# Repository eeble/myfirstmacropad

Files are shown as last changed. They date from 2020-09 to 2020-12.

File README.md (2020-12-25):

# myfirstmacropad
My First Macro Pad

I'll try to keep this updated.

<br />This work is licensed under a <a rel="license" href="http://creativecommons.org/licenses/by-sa/4.0/">Creative Commons Attribution-ShareAlike 4.0 International License</a>.

This macropad will use QMK as its firmware. QMK is also open source and available from https://qmk.fm/

### Front and Back renders
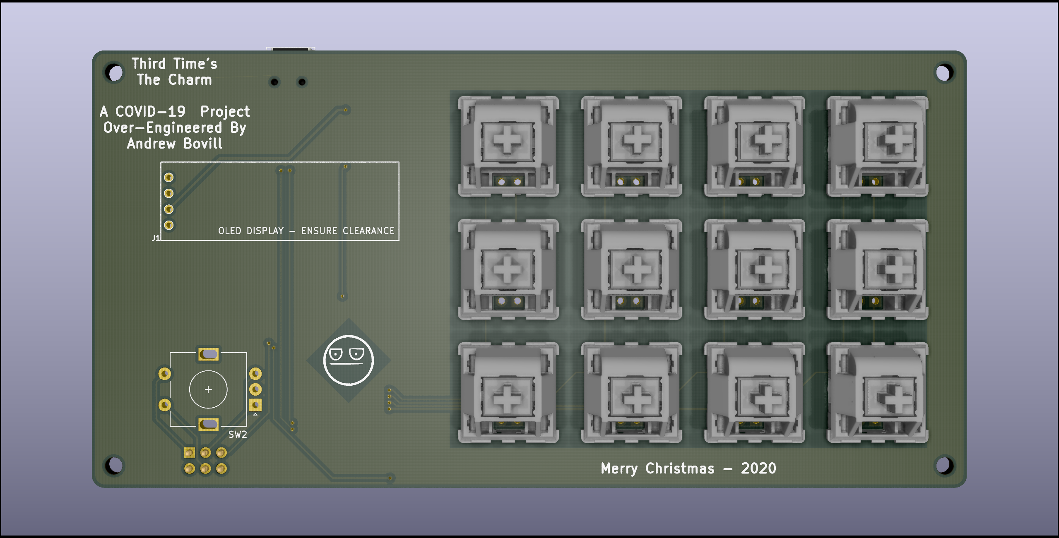
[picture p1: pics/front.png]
Front

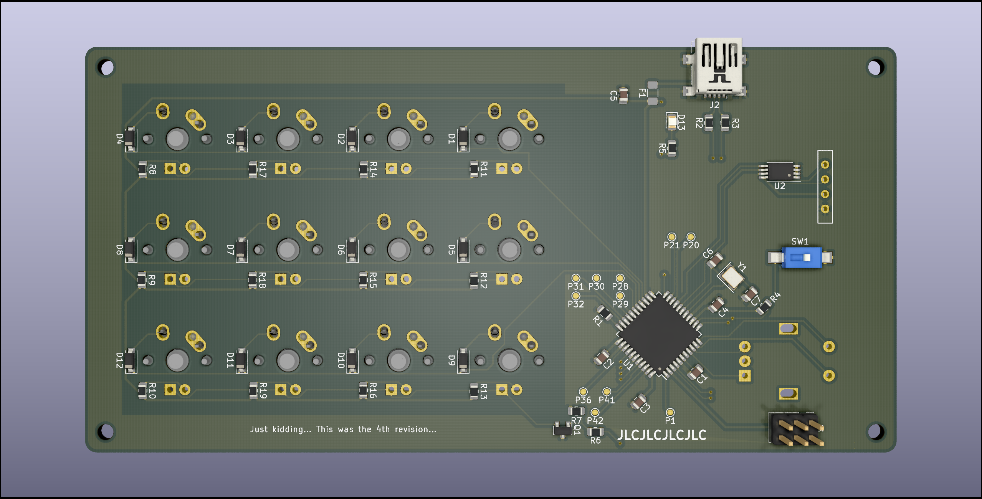
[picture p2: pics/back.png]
Back


### BOM
Interactive [BOM](kicad/bom/ibom.html)

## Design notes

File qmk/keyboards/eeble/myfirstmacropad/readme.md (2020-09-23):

# myfirstmacropad

dumbpad

A 4x4 macro/numpad with rotary encoder.

Keyboard Maintainer: [imchipwood](https://github.com/imchipwood)

PCB repository: https://github.com/imchipwood/dumbpad

Make example for this keyboard (after setting up your build environment):

    make dumbpad:default

Program with:

    make dumbpad:default:avrdude

See the [build environment setup](https://docs.qmk.fm/#/getting_started_build_tools) and the [make instructions](https://docs.qmk.fm/#/getting_started_make_guide) for more information. Brand new to QMK? Start with our [Complete Newbs Guide](https://docs.qmk.fm/#/newbs).

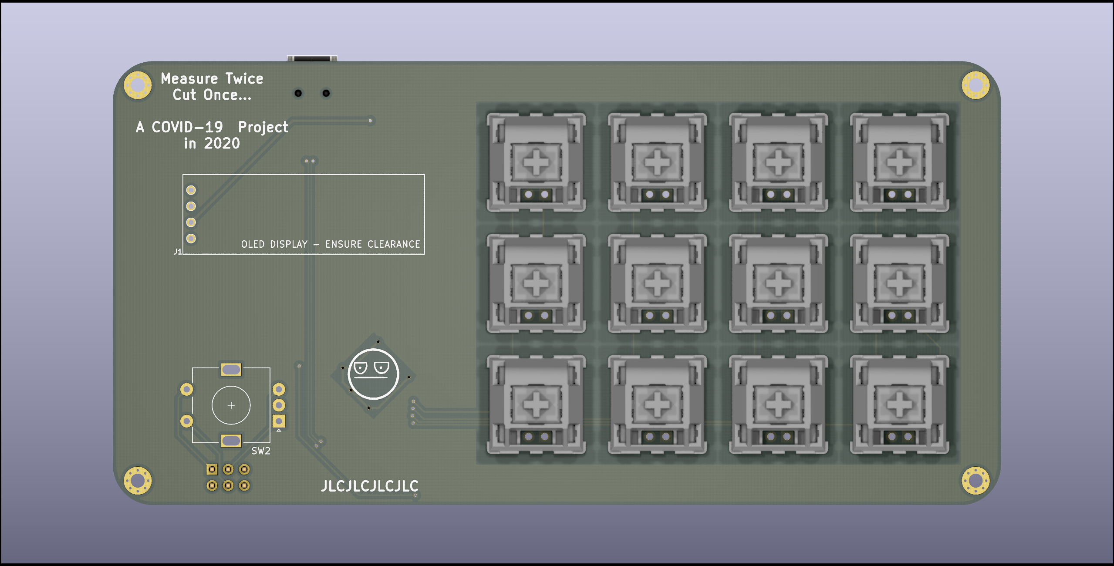
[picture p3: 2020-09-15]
kicad/pics/front.png

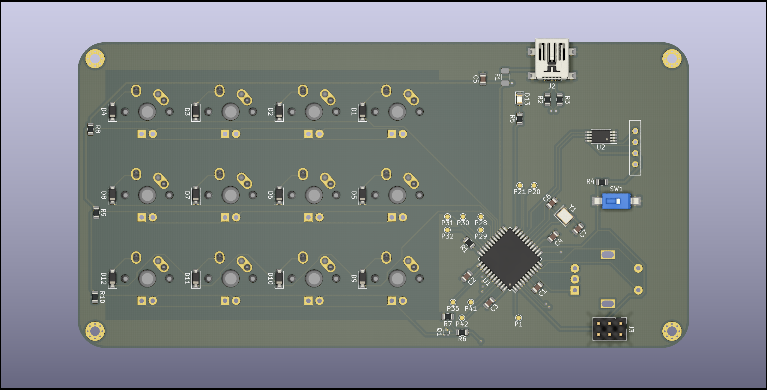
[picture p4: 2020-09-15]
kicad/pics/back.png

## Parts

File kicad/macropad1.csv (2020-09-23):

Id | Designator | Package | Quantity | Designation | Supplier and ref
1 | U1 | TQFP-44_10x10mm_P0.8mm | 1 | ATmega32U4-AU
2 | J2 | USB_Mini-B_Lumberg_2486_01_Horizontal | 1 | USB_B_Mini
3 | MX1,MX2,MX3,MX4,MX5,MX6,MX7,MX8,MX9,MX10,MX11,MX12 | MX-1U | 12 | MX-LED
4 | REF**,REF**,REF**,REF** | MountingHole_2.2mm_M2_Pad_Via | 4 | MountingHole_2.2mm_M2_Pad_Via
5 | SW2 | RotaryEncoder_Alps_EC11E-Switch_Vertical_H20mm | 1 | Rotary_Encoder_Switch
6 | G*** | unamused_sm | 1 | LOGO
7 | J1 | OLED_0.91in_4pin | 1 | Conn_01x04
8 | R3,R2 | R_0805_2012Metric | 2 | 22
9 | Y1 | Crystal_SMD_3225-4Pin_3.2x2.5mm_HandSoldering | 1 | 16Mhz
10 | SW1 | SW_SPST_REED_CT05-XXXX-G1 | 1 | SW_Reed
11 | R4,R1 | R_0805_2012Metric | 2 | 10k
12 | F1 | Fuse_1206_3216Metric | 1 | 500mA
13 | D12,D11,D10,D9,D8,D7,D6,D5,D4,D3,D2,D1 | D_SOD-123 | 12 | D_Small
14 | C7,C6 | C_0805_2012Metric | 2 | 22pF
15 | C5 | C_0805_2012Metric | 1 | 10uF
16 | C4,C3,C2 | C_0805_2012Metric | 3 | 0.1uF
17 | C1 | C_0805_2012Metric | 1 | 1uF

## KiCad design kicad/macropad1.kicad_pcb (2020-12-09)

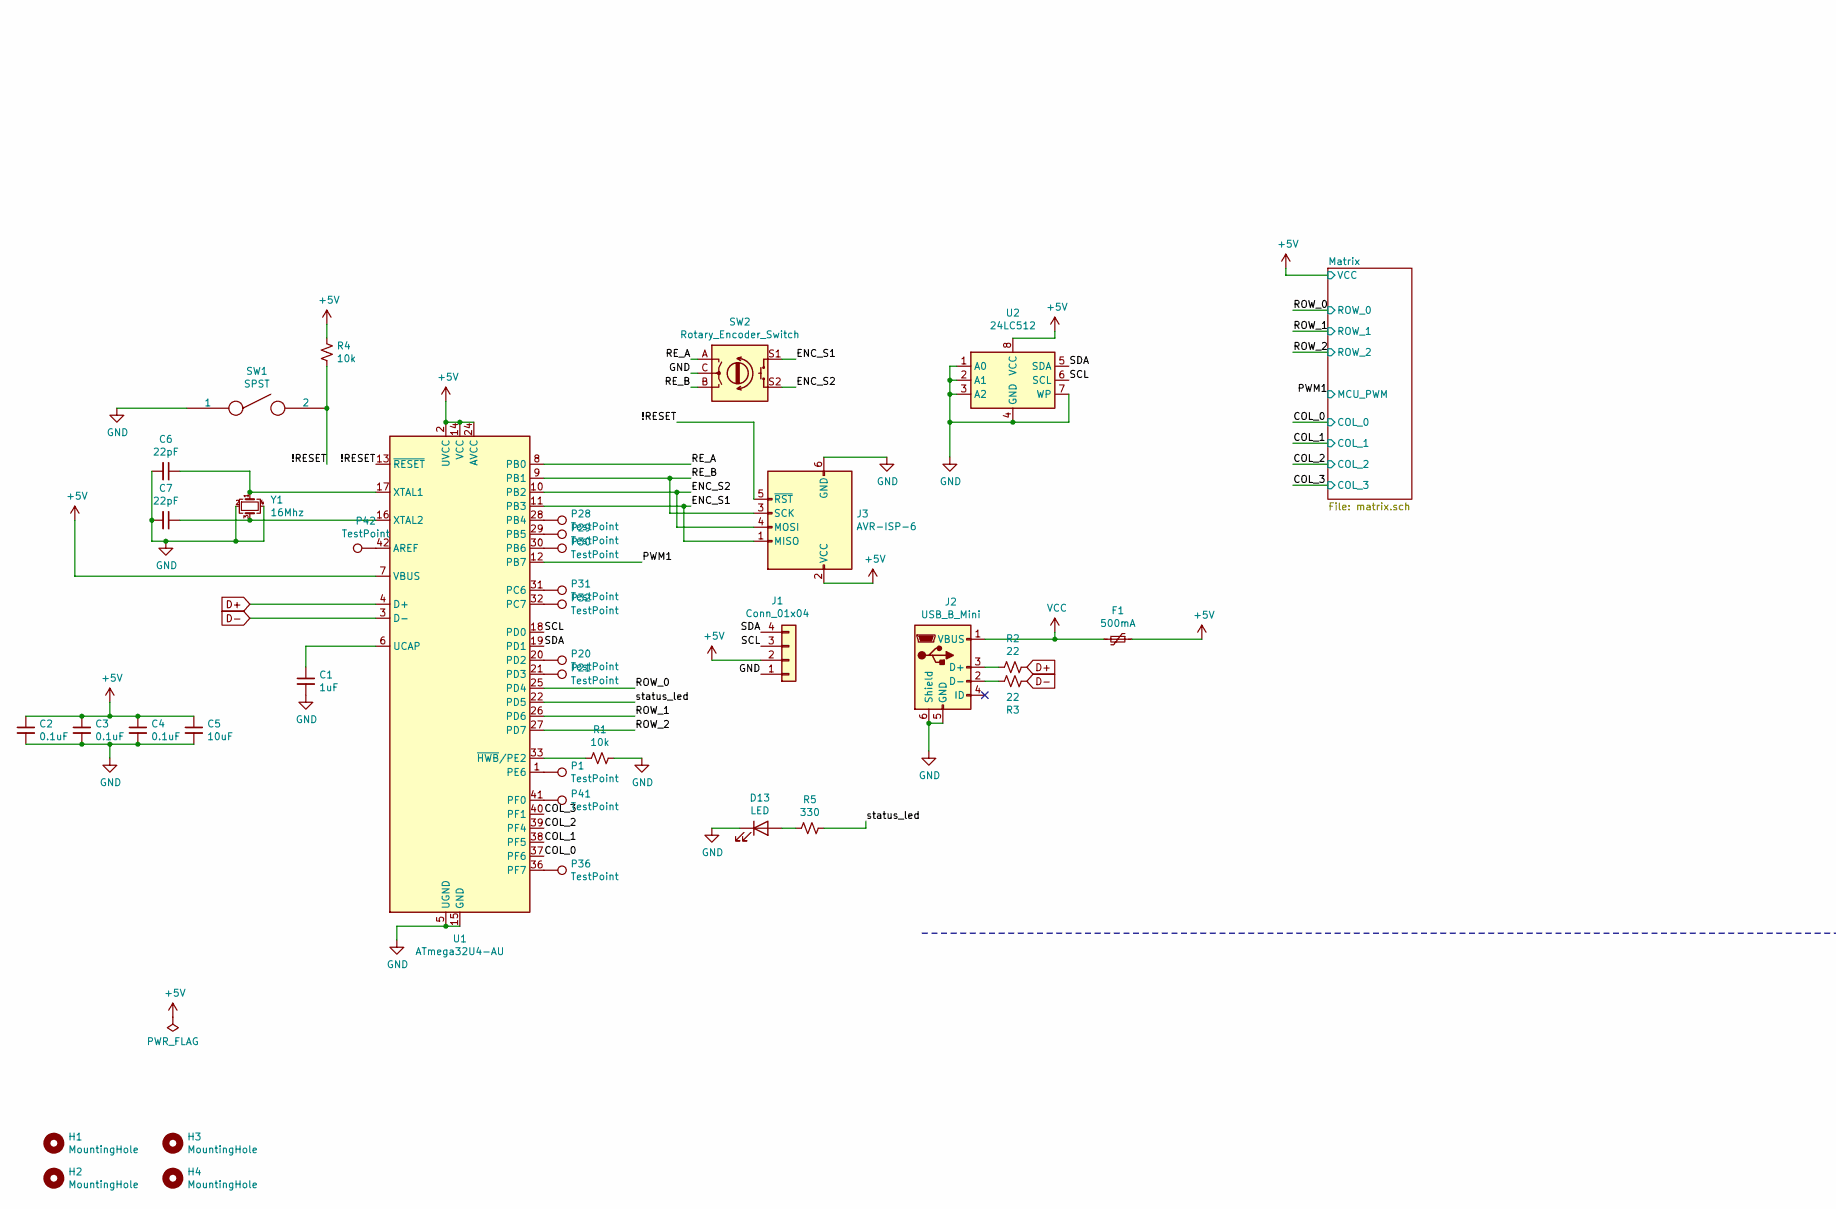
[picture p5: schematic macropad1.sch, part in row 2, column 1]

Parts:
C1: 1uF; C_0805_2012Metric
C2, C3, C4: 0.1uF; C_0805_2012Metric
C5: 10uF; C_0805_2012Metric
C6, C7: 22pF; C_0805_2012Metric
D13: LED; LED_0805_2012Metric
F1: 500mA; Fuse_1206_3216Metric
H1, H2, H3, H4: MountingHole; MountingHole_2.7mm_M2.5
J1: Conn_01x04; OLED_0.91in_4pin
J2: USB_B_Mini; USB_Mini-B_Lumberg_2486_01_Horizontal
J3: AVR-ISP-6; PinHeader_2x03_P2.54mm_Vertical
P1, P20, P21, P28, P29, P30, P31, P32, P36, P41, P42: TestPoint; TestPoint_Pad_D1.0mm
R1, R4: 10k; R_0805_2012Metric
R2, R3: 22; R_0805_2012Metric
R5: 330; R_0805_2012Metric
SW1: SPST; SW_SPST_REED_CT05-XXXX-G1
SW2: Rotary_Encoder_Switch; RotaryEncoder_Alps_EC11E-Switch_Vertical_H20mm
U1: ATmega32U4-AU; TQFP-44_10x10mm_P0.8mm
U2: 24LC512; TSSOP-8_4.4x3mm_P0.65mm
Y1: 16Mhz; Crystal_SMD_3225-4Pin_3.2x2.5mm

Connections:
+5V: C2.1, C3.1, C4.1, C5.1, F1.1, J1.2, J3.2 (VCC), R4.1, U1.2 (UVCC), U1.7 (VBUS), U1.14 (VCC), U1.24 (AVCC), U1.34 (VCC), U1.44 (AVCC), U2.8 (VCC); also elsewhere on the board
/!RESET: J3.5 (~RST), R4.2, SW1.2, U1.13 (~RESET)
/COL_0: U1.37 (PF6); also elsewhere on the board
/COL_1: U1.38 (PF5); also elsewhere on the board
/COL_2: U1.39 (PF4); also elsewhere on the board
/COL_3: U1.40 (PF1); also elsewhere on the board
/ENC_S1: J3.1 (MISO), SW2.S1, U1.11 (PB3)
/ENC_S2: J3.4 (MOSI), SW2.S2, U1.10 (PB2)
/PWM1: U1.12 (PB7); also elsewhere on the board
/RE_A: SW2.A, U1.8 (PB0)
/RE_B: J3.3 (SCK), SW2.B, U1.9 (PB1)
/ROW_0: U1.25 (PD4); also elsewhere on the board
/ROW_1: U1.26 (PD6); also elsewhere on the board
/ROW_2: U1.27 (PD7); also elsewhere on the board
/SCL: J1.3, U1.18 (PD0), U2.6 (SCL)
/SDA: J1.4, U1.19 (PD1), U2.5 (SDA)
/status_led: R5.1, U1.22 (PD5)
D+: R2.1, U1.4 (D+)
D-: R3.2, U1.3 (D-)
GND: C1.2, C2.2, C3.2, C4.2, C5.2, C6.2, C7.2, D13.1 (K), J1.1, J2.5 (GND), J2.6 (Shield), J3.6 (GND), R1.1, SW1.1, SW2.C, U1.5 (UGND), U1.15 (GND), U1.23 (GND), U1.35 (GND), U1.43 (GND), U2.1 (A0), U2.2 (A1), U2.3 (A2), U2.4 (GND), U2.7 (WP), Y1.2, Y1.4; also elsewhere on the board
unnamed: C1.1, U1.6 (UCAP)
unnamed: C6.1, U1.17 (XTAL1), Y1.1
unnamed: C7.1, U1.16 (XTAL2), Y1.3
unnamed: D13.2 (A), R5.2
unnamed: J2.2 (D-), R3.1
unnamed: J2.3 (D+), R2.2
unnamed: P1.1, U1.1 (PE6)
unnamed: P20.1, U1.20 (PD2)
unnamed: P21.1, U1.21 (PD3)
unnamed: P28.1, U1.28 (PB4)
unnamed: P29.1, U1.29 (PB5)
unnamed: P30.1, U1.30 (PB6)
unnamed: P31.1, U1.31 (PC6)
unnamed: P32.1, U1.32 (PC7)
unnamed: P36.1, U1.36 (PF7)
unnamed: P41.1, U1.41 (PF0)
unnamed: P42.1, U1.42 (AREF)
unnamed: R1.2, U1.33 (~HWB~/PE2)
VCC: F1.2, J2.1 (VBUS)

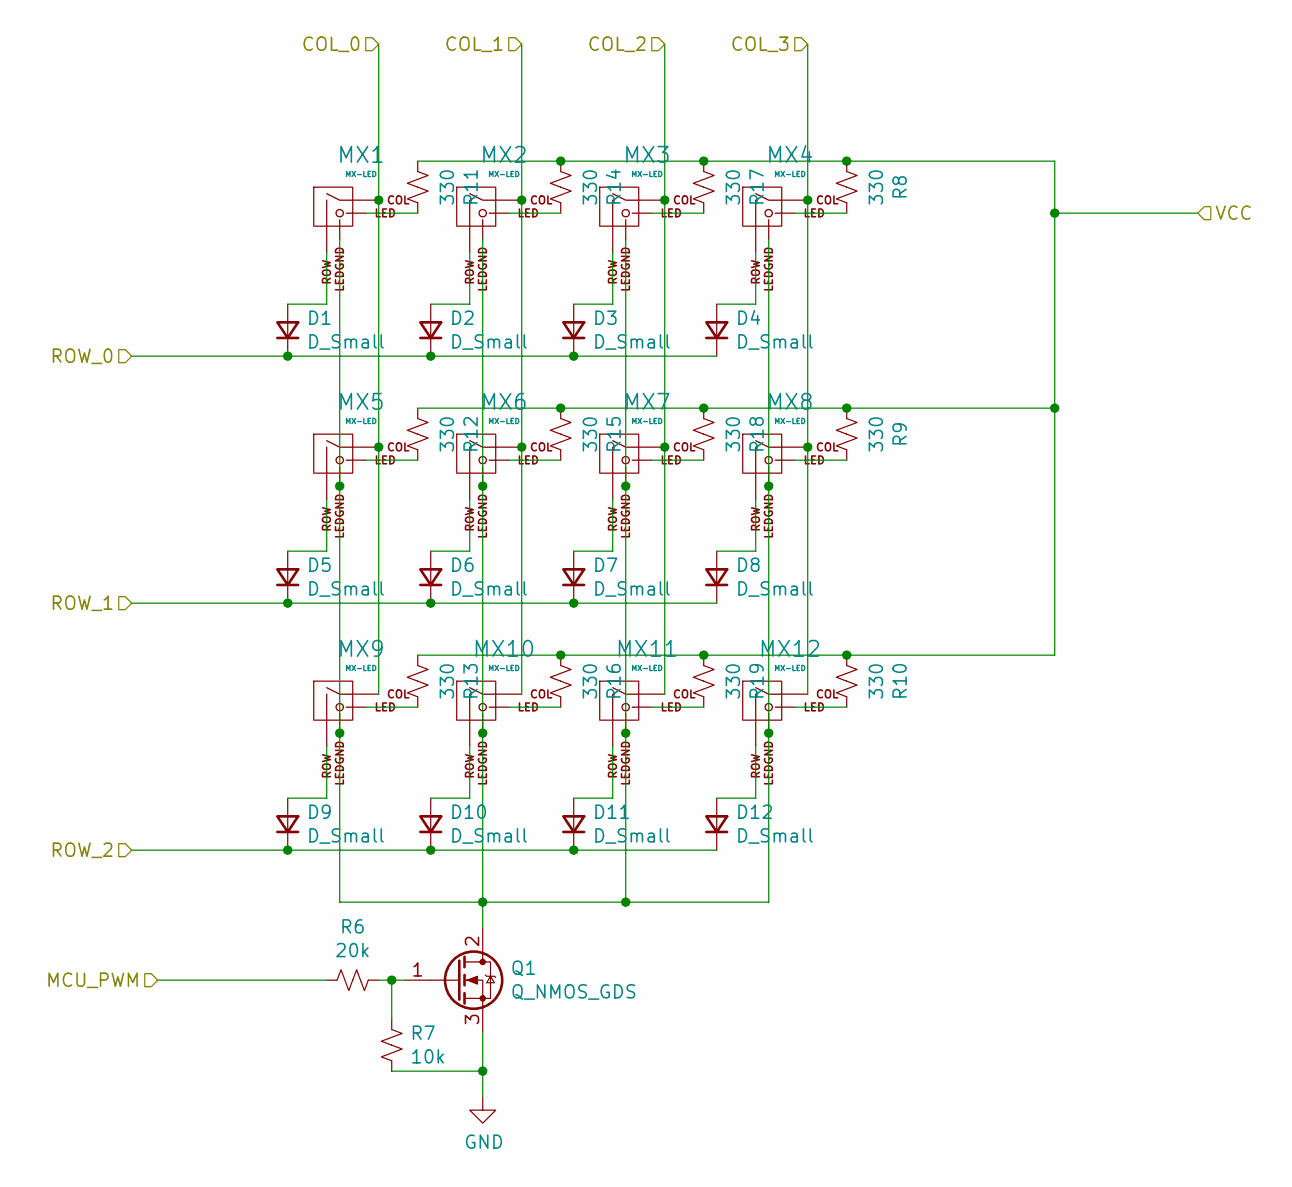
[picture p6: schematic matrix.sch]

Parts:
D1, D2, D3, D4, D5, D6, D7, D8, D9, D10, D11, D12: D_Small; D_SOD-123
MX1, MX2, MX3, MX4, MX5, MX6, MX7, MX8, MX9, MX10, MX11, MX12: MX-LED; MX-1U
Q1: Q_NMOS_GDS; SOT-23
R6: 20k; R_0805_2012Metric
R7: 10k; R_0805_2012Metric
R8, R9, R10, R11, R12, R13, R14, R15, R16, R17, R18, R19: 330; R_0805_2012Metric

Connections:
+5V: R8.2, R9.2, R10.2, R11.2, R12.2, R13.2, R14.2, R15.2, R16.2, R17.2, R18.2, R19.2; also elsewhere on the board
/COL_0: MX1.1 (COL), MX5.1 (COL), MX9.1 (COL); also elsewhere on the board
/COL_1: MX2.1 (COL), MX6.1 (COL), MX10.1 (COL); also elsewhere on the board
/COL_2: MX3.1 (COL), MX7.1 (COL), MX11.1 (COL); also elsewhere on the board
/COL_3: MX4.1 (COL), MX8.1 (COL), MX12.1 (COL); also elsewhere on the board
/PWM1: R6.2; also elsewhere on the board
/ROW_0: D1.1 (K), D2.1 (K), D3.1 (K), D4.1 (K); also elsewhere on the board
/ROW_1: D5.1 (K), D6.1 (K), D7.1 (K), D8.1 (K); also elsewhere on the board
/ROW_2: D9.1 (K), D10.1 (K), D11.1 (K), D12.1 (K); also elsewhere on the board
GND: Q1.3 (S), R7.2; also elsewhere on the board
unnamed: D1.2 (A), MX1.2 (ROW)
unnamed: D2.2 (A), MX2.2 (ROW)
unnamed: D3.2 (A), MX3.2 (ROW)
unnamed: D4.2 (A), MX4.2 (ROW)
unnamed: D5.2 (A), MX5.2 (ROW)
unnamed: D6.2 (A), MX6.2 (ROW)
unnamed: D7.2 (A), MX7.2 (ROW)
unnamed: D8.2 (A), MX8.2 (ROW)
unnamed: D9.2 (A), MX9.2 (ROW)
unnamed: D10.2 (A), MX10.2 (ROW)
unnamed: D11.2 (A), MX11.2 (ROW)
unnamed: D12.2 (A), MX12.2 (ROW)
unnamed: MX1.3 (LED), R11.1
unnamed: MX1.4 (LEDGND), MX2.4 (LEDGND), MX3.4 (LEDGND), MX4.4 (LEDGND), MX5.4 (LEDGND), MX6.4 (LEDGND), MX7.4 (LEDGND), MX8.4 (LEDGND), MX9.4 (LEDGND), MX10.4 (LEDGND), MX11.4 (LEDGND), MX12.4 (LEDGND), Q1.2 (D)
unnamed: MX2.3 (LED), R14.1
unnamed: MX3.3 (LED), R17.1
unnamed: MX4.3 (LED), R8.1
unnamed: MX5.3 (LED), R12.1
unnamed: MX6.3 (LED), R15.1
unnamed: MX7.3 (LED), R18.1
unnamed: MX8.3 (LED), R9.1
unnamed: MX9.3 (LED), R13.1
unnamed: MX10.3 (LED), R16.1
unnamed: MX11.3 (LED), R19.1
unnamed: MX12.3 (LED), R10.1
unnamed: Q1.1 (G), R6.1, R7.1

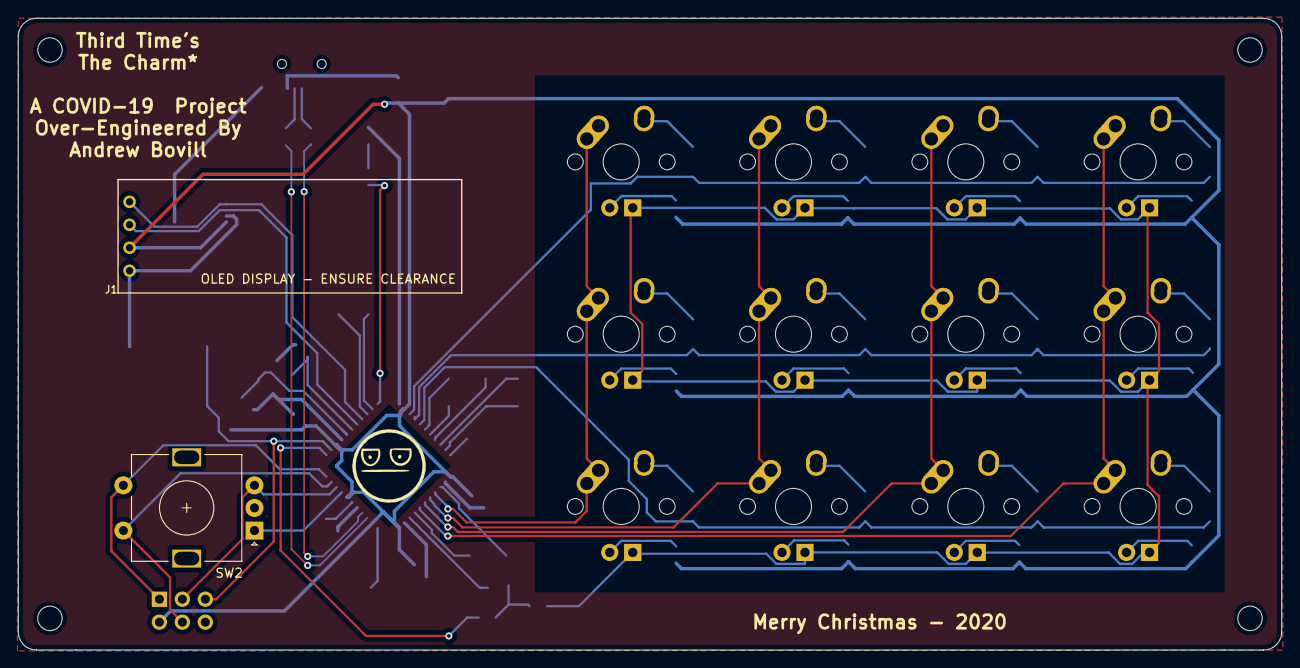
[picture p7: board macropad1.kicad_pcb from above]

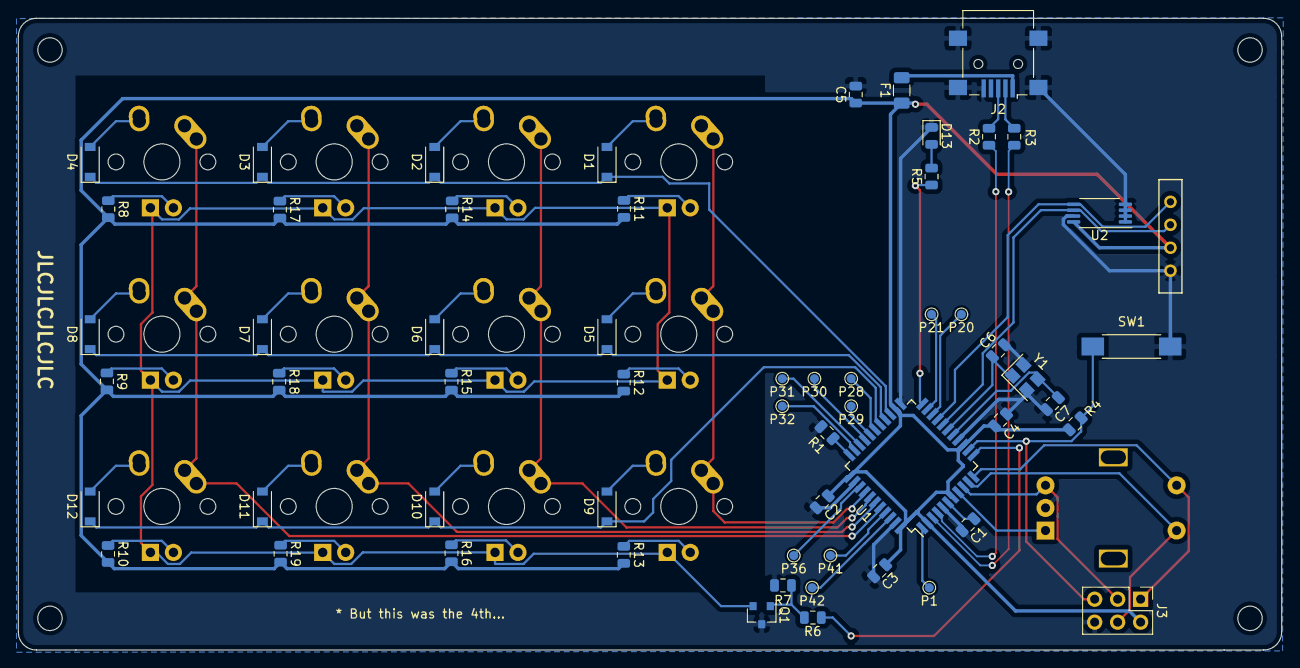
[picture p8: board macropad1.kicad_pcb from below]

Board: 2 copper layers, 139.7 x 69.8 mm, 76 parts (58 on the bottom side), 65 nets.

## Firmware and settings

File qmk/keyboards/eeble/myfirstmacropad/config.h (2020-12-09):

/*
Copyright 2019 eeble

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
You should have received a copy of the GNU General Public License
along with this program.  If not, see <http://www.gnu.org/licenses/>.
*/

#pragma once

#include "config_common.h"

/* USB Device descriptor parameter */
#define VENDOR_ID       0x1209
#define PRODUCT_ID      0x3845
#define DEVICE_VER      0x0001
#define MANUFACTURER    eeble
#define PRODUCT         eeble myfirstmacropad
#define DESCRIPTION     eeble myfirstmacropad


/*
 * Keyboard Matrix Assignments
 *
 * Change this to how you wired your keyboard
 * COLS: AVR pins used for columns, left to right
 * ROWS: AVR pins used for rows, top to bottom
 * DIODE_DIRECTION: COL2ROW = COL = Anode (+), ROW = Cathode (-, marked on diode)
 *                  ROW2COL = ROW = Anode (+), COL = Cathode (-, marked on diode)
 *
*/
#define MATRIX_ROWS 4
#define MATRIX_COLS 5
#define MATRIX_ROW_PINS { D4, D6, D7, B2 }
#define MATRIX_COL_PINS { B3, F6,F5,F4,F1 }
#define UNUSED_PINS

/* COL2ROW, ROW2COL*/
#define DIODE_DIRECTION COL2ROW

/* Rotary encoder */
#define ENCODERS_PAD_A { B0 }
#define ENCODERS_PAD_B { B1 }

/* LED layer indicators */
//#define LAYER_INDICATOR_LED_0 B3
//#define LAYER_INDICATOR_LED_1 B1

/* Bootmagic - hold down rotary encoder pushbutton while plugging in to enter bootloader */
#define BOOTMAGIC_LITE_ROW 3
#define BOOTMAGIC_LITE_COLUMN 0


/* Debounce reduces chatter (unintended double-presses) - set 0 if debouncing is not needed */
#define DEBOUNCE 5

/* define if matrix has ghost (lacks anti-ghosting diodes) */
//#define MATRIX_HAS_GHOST

/* number of backlight levels */

/* Mechanical locking support. Use KC_LCAP, KC_LNUM or KC_LSCR instead in keymap */
//#define LOCKING_SUPPORT_ENABLE
/* Locking resynchronize hack */
//#define LOCKING_RESYNC_ENABLE

/*
 * Split Keyboard specific options, make sure you have 'SPLIT_KEYBOARD = yes' in your rules.mk, and define SOFT_SERIAL_PIN.
 */
//#define SOFT_SERIAL_PIN D0 // or D1, D2, D3, E6

// #define BACKLIGHT_PIN B7
// #define BACKLIGHT_BREATHING
// #define BACKLIGHT_LEVELS 3

// #define RGB_DI_PIN E2
// #ifdef RGB_DI_PIN
//   #define RGBLED_NUM 16
//   #define RGBLIGHT_HUE_STEP 8
//   #define RGBLIGHT_SAT_STEP 8
//   #define RGBLIGHT_VAL_STEP 8
//   #define RGBLIGHT_LIMIT_VAL 255 /* The maximum brightness level */
//   #define RGBLIGHT_SLEEP  /* If defined, the RGB lighting will be switched off when the host goes to sleep */
// /*== all animations enable ==*/
//   #define RGBLIGHT_ANIMATIONS
// /*== or choose animations ==*/
//   #define RGBLIGHT_EFFECT_BREATHING
//   #define RGBLIGHT_EFFECT_RAINBOW_MOOD
//   #define RGBLIGHT_EFFECT_RAINBOW_SWIRL
//   #define RGBLIGHT_EFFECT_SNAKE
//   #define RGBLIGHT_EFFECT_KNIGHT
//   #define RGBLIGHT_EFFECT_CHRISTMAS
//   #define RGBLIGHT_EFFECT_STATIC_GRADIENT
//   #define RGBLIGHT_EFFECT_RGB_TEST
//   #define RGBLIGHT_EFFECT_ALTERNATING
// /*== customize breathing effect ==*/
//   /*==== (DEFAULT) use fixed table instead of exp() and sin() ====*/
//   #define RGBLIGHT_BREATHE_TABLE_SIZE 256      // 256(default) or 128 or 64
//   /*==== use exp() and sin() ====*/
//   #define RGBLIGHT_EFFECT_BREATHE_CENTER 1.85  // 1 to 2.7
//   #define RGBLIGHT_EFFECT_BREATHE_MAX    255   // 0 to 255
// #endif

/* If defined, GRAVE_ESC will always act as ESC when CTRL is held.
 * This is userful for the Windows task manager shortcut (ctrl+shift+esc).
 */
// #define GRAVE_ESC_CTRL_OVERRIDE

/*
 * Force NKRO
 *
 * Force NKRO (nKey Rollover) to be enabled by default, regardless of the saved
 * state in the bootmagic EEPROM settings. (Note that NKRO must be enabled in the
 * makefile for this to work.)
 *
 * If forced on, NKRO can be disabled via magic key (default = LShift+RShift+N)
 * until the next keyboard reset.
 *
 * NKRO may prevent your keystrokes from being detected in the BIOS, but it is
 * fully operational during normal computer usage.
 *
 * For a less heavy-handed approach, enable NKRO via magic key (LShift+RShift+N)
 * or via bootmagic (hold SPACE+N while plugging in the keyboard). Once set by
 * bootmagic, NKRO mode will always be enabled until it is toggled again during a
 * power-up.
 *
 */
//#define FORCE_NKRO

/*
 * Magic Key Options
 *
 * Magic keys are hotkey commands that allow control over firmware functions of
 * the keyboard. They are best used in combination with the HID Listen program,
 * found here: https://www.pjrc.com/teensy/hid_listen.html
 *
 * The options below allow the magic key functionality to be changed. This is
 * useful if your keyboard/keypad is missing keys and you want magic key support.
 *
 */

/* key combination for magic key command */
/* defined by default; to change, uncomment and set to the combination you want */
// #define IS_COMMAND() (get_mods() == (MOD_BIT(KC_LSHIFT) | MOD_BIT(KC_RSHIFT)))

/* control how magic key switches layers */
//#define MAGIC_KEY_SWITCH_LAYER_WITH_FKEYS  true
//#define MAGIC_KEY_SWITCH_LAYER_WITH_NKEYS  true
//#define MAGIC_KEY_SWITCH_LAYER_WITH_CUSTOM false
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

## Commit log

2020-08-29 Initial import
    [macropad1.kicad_pcb, macropad1.sch, matrix.sch]
2020-08-31 Ready for prototyping
    [macropad1.kicad_pcb, macropad1.sch, matrix.sch]
2020-09-02 Added artwork lib and eeprom
    [macropad1.kicad_pcb, macropad1.sch]
2020-09-02 Added board pics
    [macropad1.kicad_pcb]
2020-09-13 Fixes D+/D- swap and adds ISP header
    Also moves some components around for better layout
    [macropad1.kicad_pcb, macropad1.sch]
2020-09-13 Adds testpads for all unused pins on MCU
    [macropad1.kicad_pcb, macropad1.sch]
2020-09-13 Repours copper fill and updates images
    [macropad1.kicad_pcb]
2020-09-13 Reworks location of traces for ISP header
    [macropad1.kicad_pcb]
2020-09-13 Re-ran DRC
    [macropad1.kicad_pcb]
2020-09-13 Adds single color backlighting to each key :)
    [macropad1.kicad_pcb, macropad1.sch, matrix.sch]
2020-09-13 Produced files for JCLPCB
    [macropad1.kicad_pcb]
2020-09-15 Adds switches to the 3d model
    [macropad1.kicad_pcb]
2020-09-23 Adds kicad directory for kicad stuff
    [macropad1.csv, macropad1.kicad_pcb, macropad1.sch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]
2020-09-25 fixes matrix and adds oled poc
    [config.h]
2020-12-09 Adds iBom and final revision of board
    Puts holes in the right place for the case
    Adds proper backlight support with a properly sized mosfet (tiny)
    Double checks dimensions
    [macropad1.kicad_pcb, macropad1.sch, matrix.sch]
2020-12-09 Adds link to BOM in README.md
2020-12-09 re-saved file
    [macropad1.kicad_pcb]

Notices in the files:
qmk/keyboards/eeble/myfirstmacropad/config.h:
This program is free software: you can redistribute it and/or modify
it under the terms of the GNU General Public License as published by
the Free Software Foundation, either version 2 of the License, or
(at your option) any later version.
